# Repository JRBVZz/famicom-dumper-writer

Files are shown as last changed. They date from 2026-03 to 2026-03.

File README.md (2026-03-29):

### Famicom Dumper - дампер/программатор для картриджей Famicom/Dendy

Цель проекта — создание идеального симулятора шины данных Famicom. Он использует очень точную симуляцию цикла M2 и FSMC для доступа к памяти PRG и CHR. Кроме того, этот дампер имеет высокую скорость чтения/записи больших многоигровок.  
  
Главные отличия данного форка от оригинального проекта: полностью изменена трассировка; выводные светодиоды заменены на SMD; есть возможность установки на выбор THT или SMD версии кварцевого резонатора; убран разъем NES.  
  
В папке **STM32-Dumper** находится KiCad проект и гербер файлы для производства.  
  
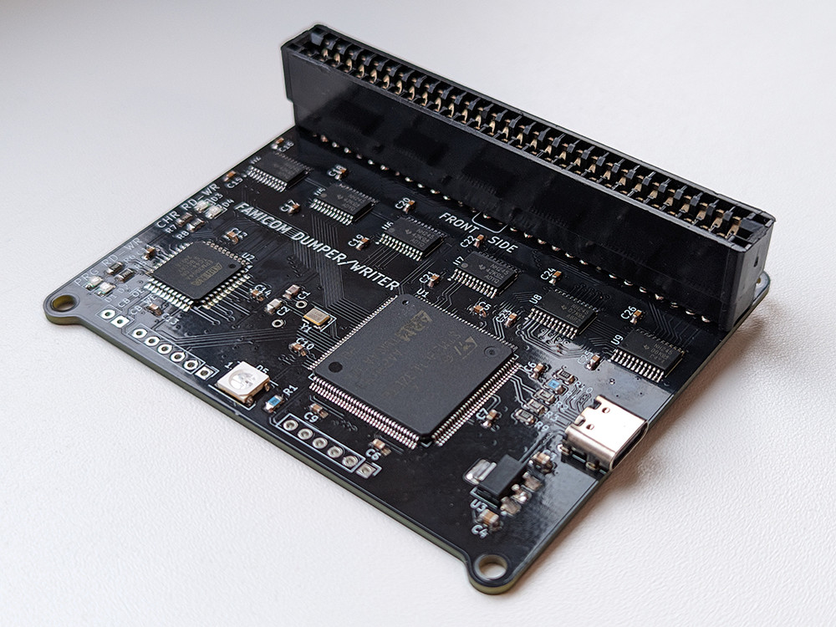
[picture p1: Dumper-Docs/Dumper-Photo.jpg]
Dumper-Photo

  
Проект создан в [**KiCad 9**](https://www.kicad.org/).

### Сборка

#### BoM и Schematic
[BoM](Dumper-Docs/Dumper-BOM.jpg)  
  
[Schematic](Dumper-Docs/STM32-Dumper-Schematic.pdf)

Выберите какой кварцевый резонатор ставить - SMD **Y1**, или THT **Y2**.  
Вместо шифтера **U7** можно установить два резистора **R11, R12**.  

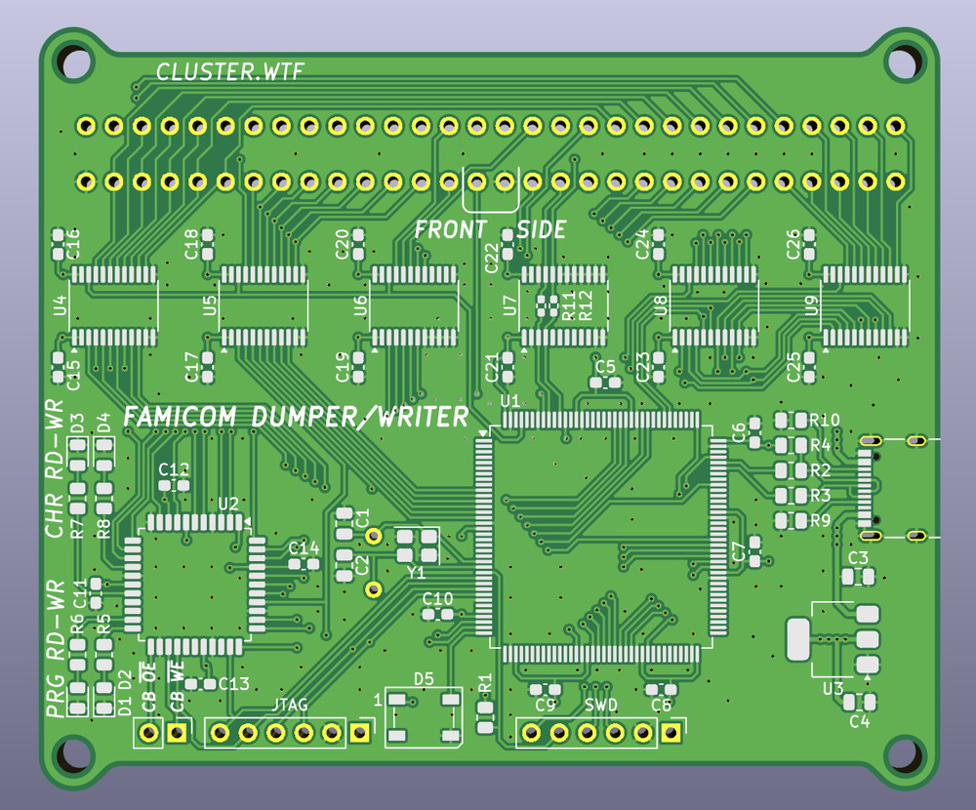
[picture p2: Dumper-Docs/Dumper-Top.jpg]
Dumper-Top


#### Firmware
В папке **Dumper-Firmware** находятся файлы для прошивки STM32 и EPM3064:  
**FamicomDumper.pof** - файл для прошивки EPM3064 с помощью USB-Blaster. Исходники находятся в архиве Dumper-CPLD.zip  
**FamicomDumperBootloader.bin** - бутлоадер для STM32, для прошивки можно использовать программу STM32 ST-LINK Utility и дешёвый донгл ST-LINK. Вручную укажите адрес для записи **0x08000000**.  
**FamicomDumper.bin** - основная программа для STM32. Вручную укажите адрес для записи **0x08040000**.  

### Software

[https://github.com/ClusterM/famicom-dumper-client](https://github.com/ClusterM/famicom-dumper-client)

#### P.S.

Мне не очень нравится идея преобразования сигналов до уровня 5В. Да, для старых картриджей это нормально, но современные дешевые многоигровки используют чипы с питанием 3.3В и в подавляющем большинстве случаев не имеют преобразователей уровней. Поэтому 5В сигналы для них, мягко говоря, не полезны. Как вариант, использовать 74LVC245A вместо 74LVC8T245.

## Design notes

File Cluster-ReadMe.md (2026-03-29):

# Famicom/NES Dumper/Writer

## Overview

This is a powerfull dumper/writer for Famicom/NES cartridges and Famicom Disc System cards. The goal of the project is to create an ideal famicom data bus simulator. It's using a very accurate M2 cycle simulation and FSMC (Flexible Static Memory Controller) to access PRG and CHR memory. FSMC is precisely synchronized with the M2 clock signal using a CPLD chip. Also, this device is very fast.





COOLBOY writing using GPIO pins

Video about dumper development (English subtitles):

Video preview (https://youtu.be/j_rteVX5q-g)

You can use it to:

* Dump cartridges, so you can play copy of your cartridge on emulator.
* Dump reset-based cartridges, there is command to simulate reset press.
* Dump cartridges that requires a continuous clock on M2 pin.
* Use it with [very flexible and multiplatform client](https://github.com/ClusterM/famicom-dumper-client), it's using C# scripts.
* Read/write battery backed saves, so that you can continue your saved game on emulator/console and vice-versa.
* (Re)write [COOLGIRL](https://github.com/ClusterM/coolgirl-famicom-multicard) cartridges.
* (Re)write ultracheap chinese [COOLBOY (AA6023 chip based)](https://www.nesdev.org/wiki/NES_2.0_Mapper_268) cartridges (mapper 268). Soldering is required for a cheap cartridges but it's very simple. Some more expensive cartridges can be rewritten without soldering.
* (Re)write UNROM-512 cartridges (RetroUSB, mapper 30).
* Read and write Famicom Disk System cards using FDS drive with the RAM adapter.
* Test your cartridges.
* Do some reverse engineering.
* Anything else that requires Famicom/NES bus simulation.

## Schematic

Schematic

Bill of Materials:

BoM

## Firmware

You need to write firmware to two chips: the STM32F103ZET microcontroller and the EPM3064 CPLD. But actually you need only to flash bootloader to STM32 using ST-Link programmer. Using bootloader you can flash both firmwares: to the STM32F103ZET and to the EPM3064.

How to use bootloader:
* Disconnect device from USB.
* Short the ground and the IRQ pins using tweezers or scissors.

* Connect the device to the USB of your PC/Mac. The RGB LED should turn green. Try again if it's not green.
* Remove tweezers/scissors quickly while the LED is green.
* The LED should turn yellow. Try again if it's not yellow.
* The device should be detected as USB drive.
* Format it to FAT32 if it's not formatted yet. You need to do it only once.
* Write SVF file with the firmware for the EPM3064 chip and BIN file with the firmware for the STM32F103ZET chip to this USB drive. You can write both at the same time.
* The RGB LED should turn white.
* Wait for some time: ~30 seconds for EPM3064 firmware, ~1 second for STM32F103ZET firmware.
* The RGB LED should turn green on success, red on some error.
* Reconnect device to your PC/Mac.

You can update the firmwares using the same way without any additional hardware (only tweezers or scissors :))

## Driver

This device shound work without any additional drivers on all modern operating systems, as virtual serial port.

## Software

[https://github.com/ClusterM/famicom-dumper-client](https://github.com/ClusterM/famicom-dumper-client)

## Donate
PayPal: cluster@cluster.wtf

https://www.donationalerts.com/r/clustermeerkat

https://boosty.to/cluster

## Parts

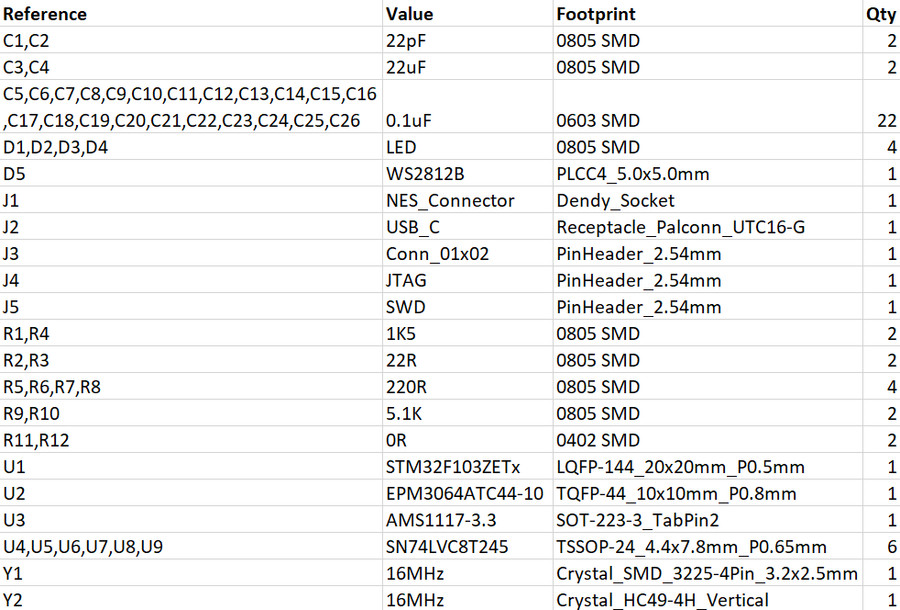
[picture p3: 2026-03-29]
Dumper-Docs/Dumper-BOM.jpg

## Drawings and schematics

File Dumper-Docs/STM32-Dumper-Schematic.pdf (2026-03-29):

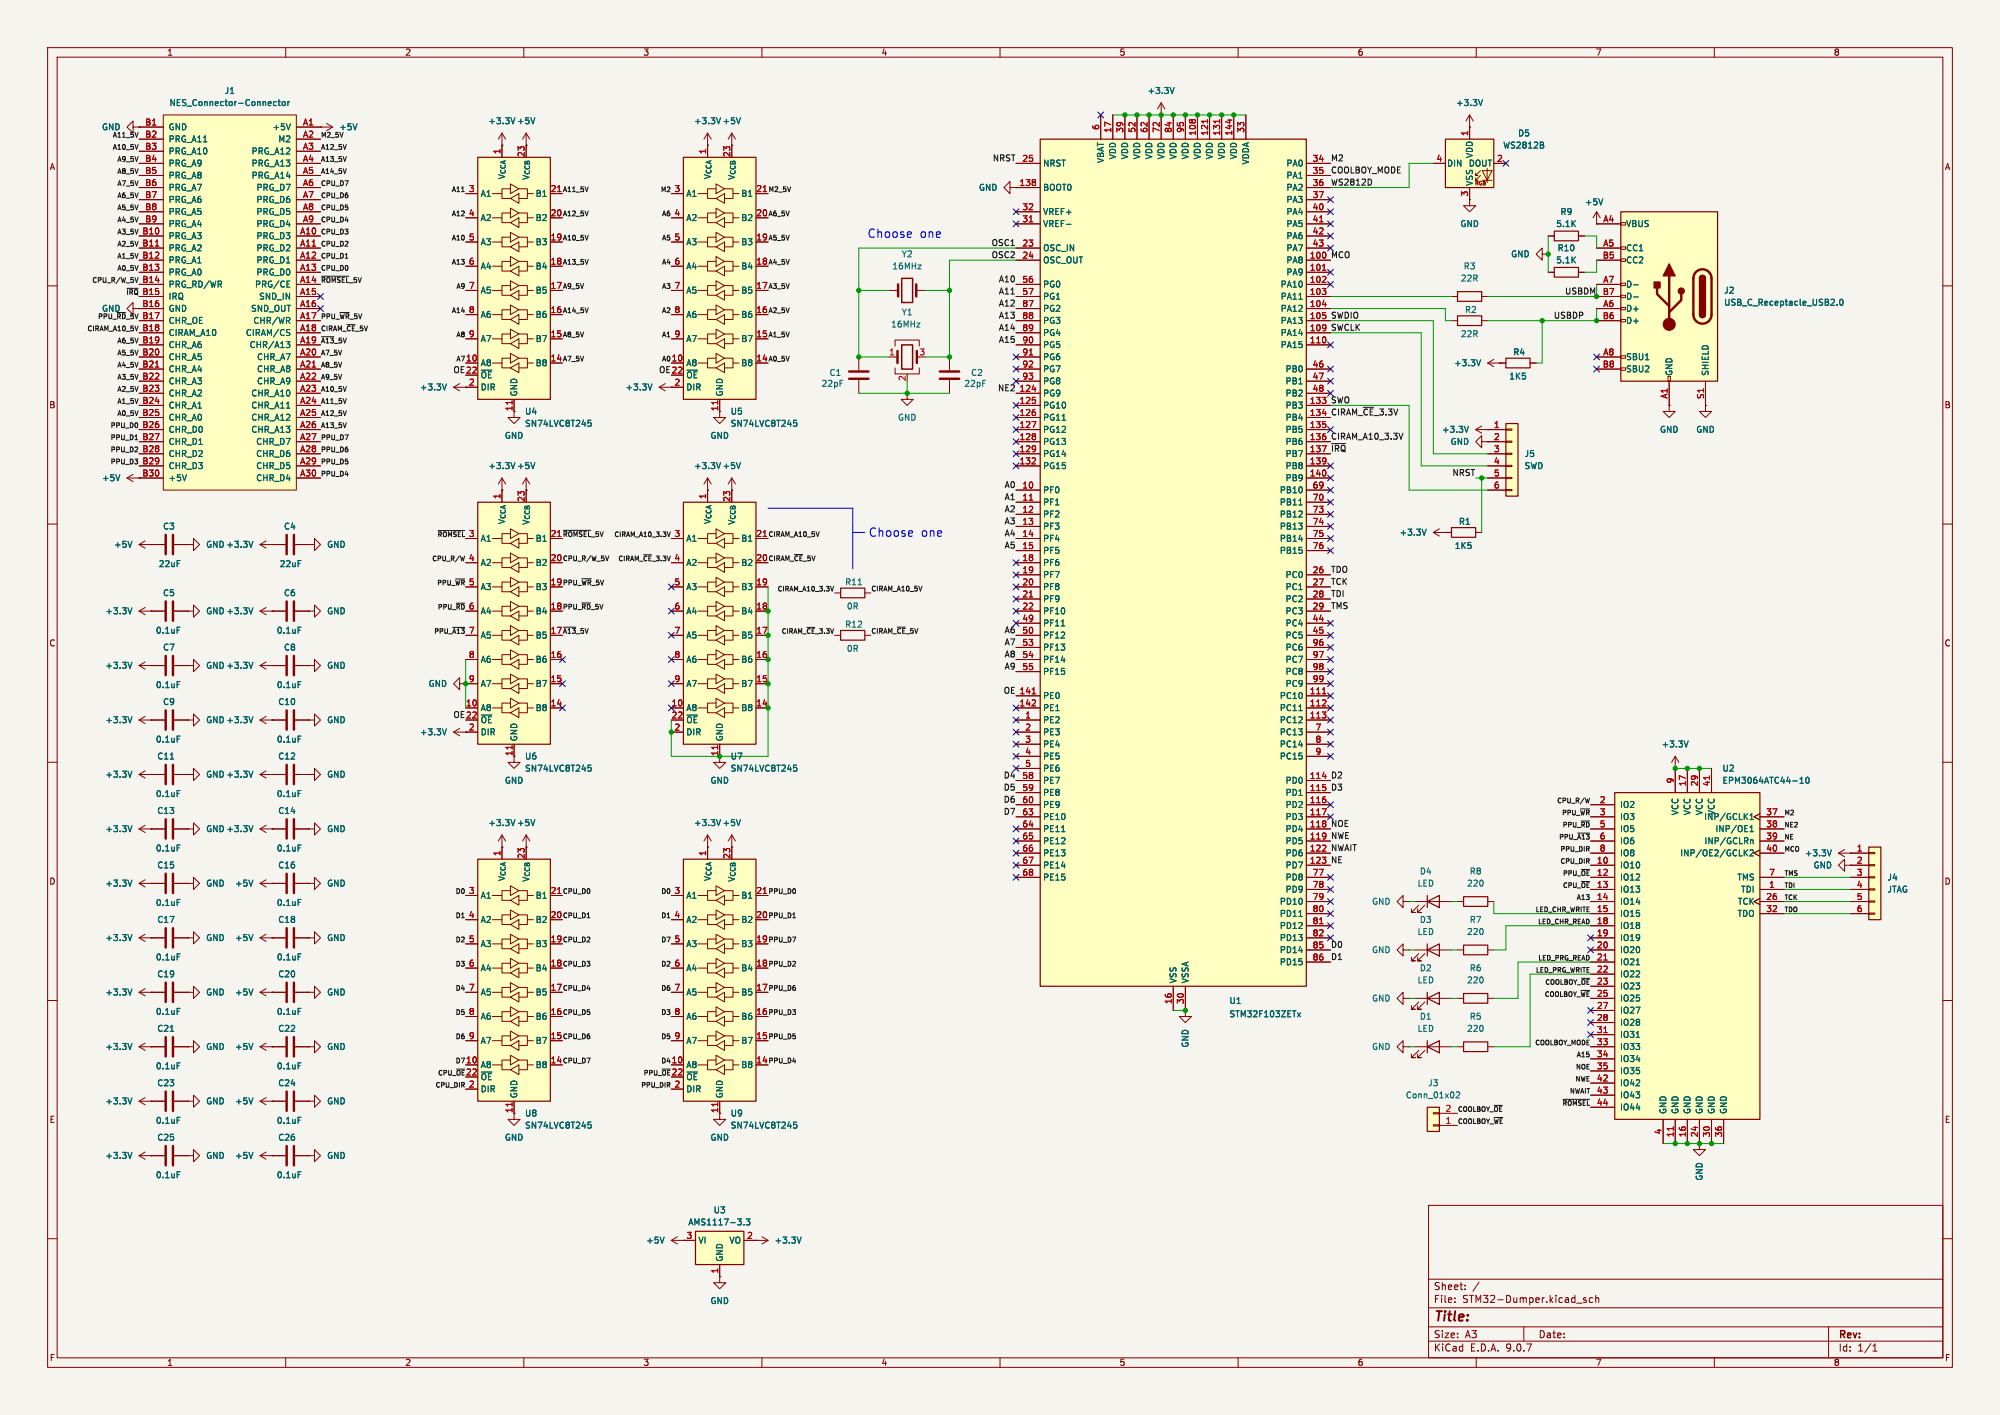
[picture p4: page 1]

6 VDD 17 VDD 39 VDD 52 VDD 62 VDD 72 VDD 84 VSS 16 VDD 95 VSSA 30 VDD 108 VDD 121 VDD 131 VDD 144 VDDA 33 PA0 34 PA1 35 PA2 36 PA3 37 PA4 40 PA5 41 PA6 42 PA7 43 PA8 100 PA9 101 PA10 102 PA11 103 PA12 104 PA13 105 PA14 109 PA15 110 PB0 46 PB1 47 PB2 48 PB3 133 PB4 134 PB5 135 PB6 136 PB7 137 PB8 139 PB9 140 PB10 69 PB11 70 PB12 73 PB13 74 PB14 75 PB15 76 PC0 26 PC1 27 PC2 28 PC3 29 PC4 44 PC5 45 PC6 96 PC7 97 PC8 98 PC9 99 PC10 111 PC11 112 PC12 113 PC13 7 PC14 8 PC15 9 PD0 114 PD1 115 PD2 116 PD3 117 PD4 118 PD5 119 PD6 122 PD7 123 PD8 77 PD9 78 PD10 79 PD11 80 PD12 81 PD13 82 PD14 85 PD15 86 U1STM32F103ZETx GND

6 VDD 17 VDD 39 VDD 52 VDD 62 VDD 72 VDD 84 VSS 16 VDD 95 VSSA 30 VDD 108 VDD 121 VDD 131 VDD 144 VDDA 33 PA0 34 PA1 35 PA2 36 PA3 37 PA4 40 PA5 41 PA6 42 PA7 43 PA8 100 PA9 101 PA10 102 PA11 103 PA12 104 PA13 105 PA14 109 PA15 110 PB0 46 PB1 47 PB2 48 PB3 133 PB4 134 PB5 135 PB6 136 PB7 137 PB8 139 PB9 140 PB10 69 PB11 70 PB12 73 PB13 74 PB14 75 PB15 76 PC0 26 PC1 27 PC2 28 PC3 29 PC4 44 PC5 45 PC6 96 PC7 97 PC8 98 PC9 99 PC10 111 PC11 112 PC12 113 PC13 7 PC14 8 PC15 9 PD0 114 PD1 115 PD2 116 PD3 117 PD4 118 PD5 119 PD6 122 PD7 123 PD8 77 PD9 78 PD10 79 PD11 80 PD12 81 PD13 82 PD14 85 PD15 86 GND

9 GND 11 VCC 17 GND 16 VCC 29 GND 24 VCC 41 GND 30 GND 36

1 VO 2 +3.3V U8SN74LVC8T245 A1 3 A2 4 A3 5 A4 6 A5 7 A6 8 A7 9 A8 10 ~{OE} 22 DIR 2 V_{CCA} 1 GND 11 V_{CCB} 23 B1 21 B2 20 B3 19 B4 18 B5 17 B6 16 B7 15 B8 14 GND

Id: 1/1 Title: File: STM32-Dumper.kicad_sch Sheet: /

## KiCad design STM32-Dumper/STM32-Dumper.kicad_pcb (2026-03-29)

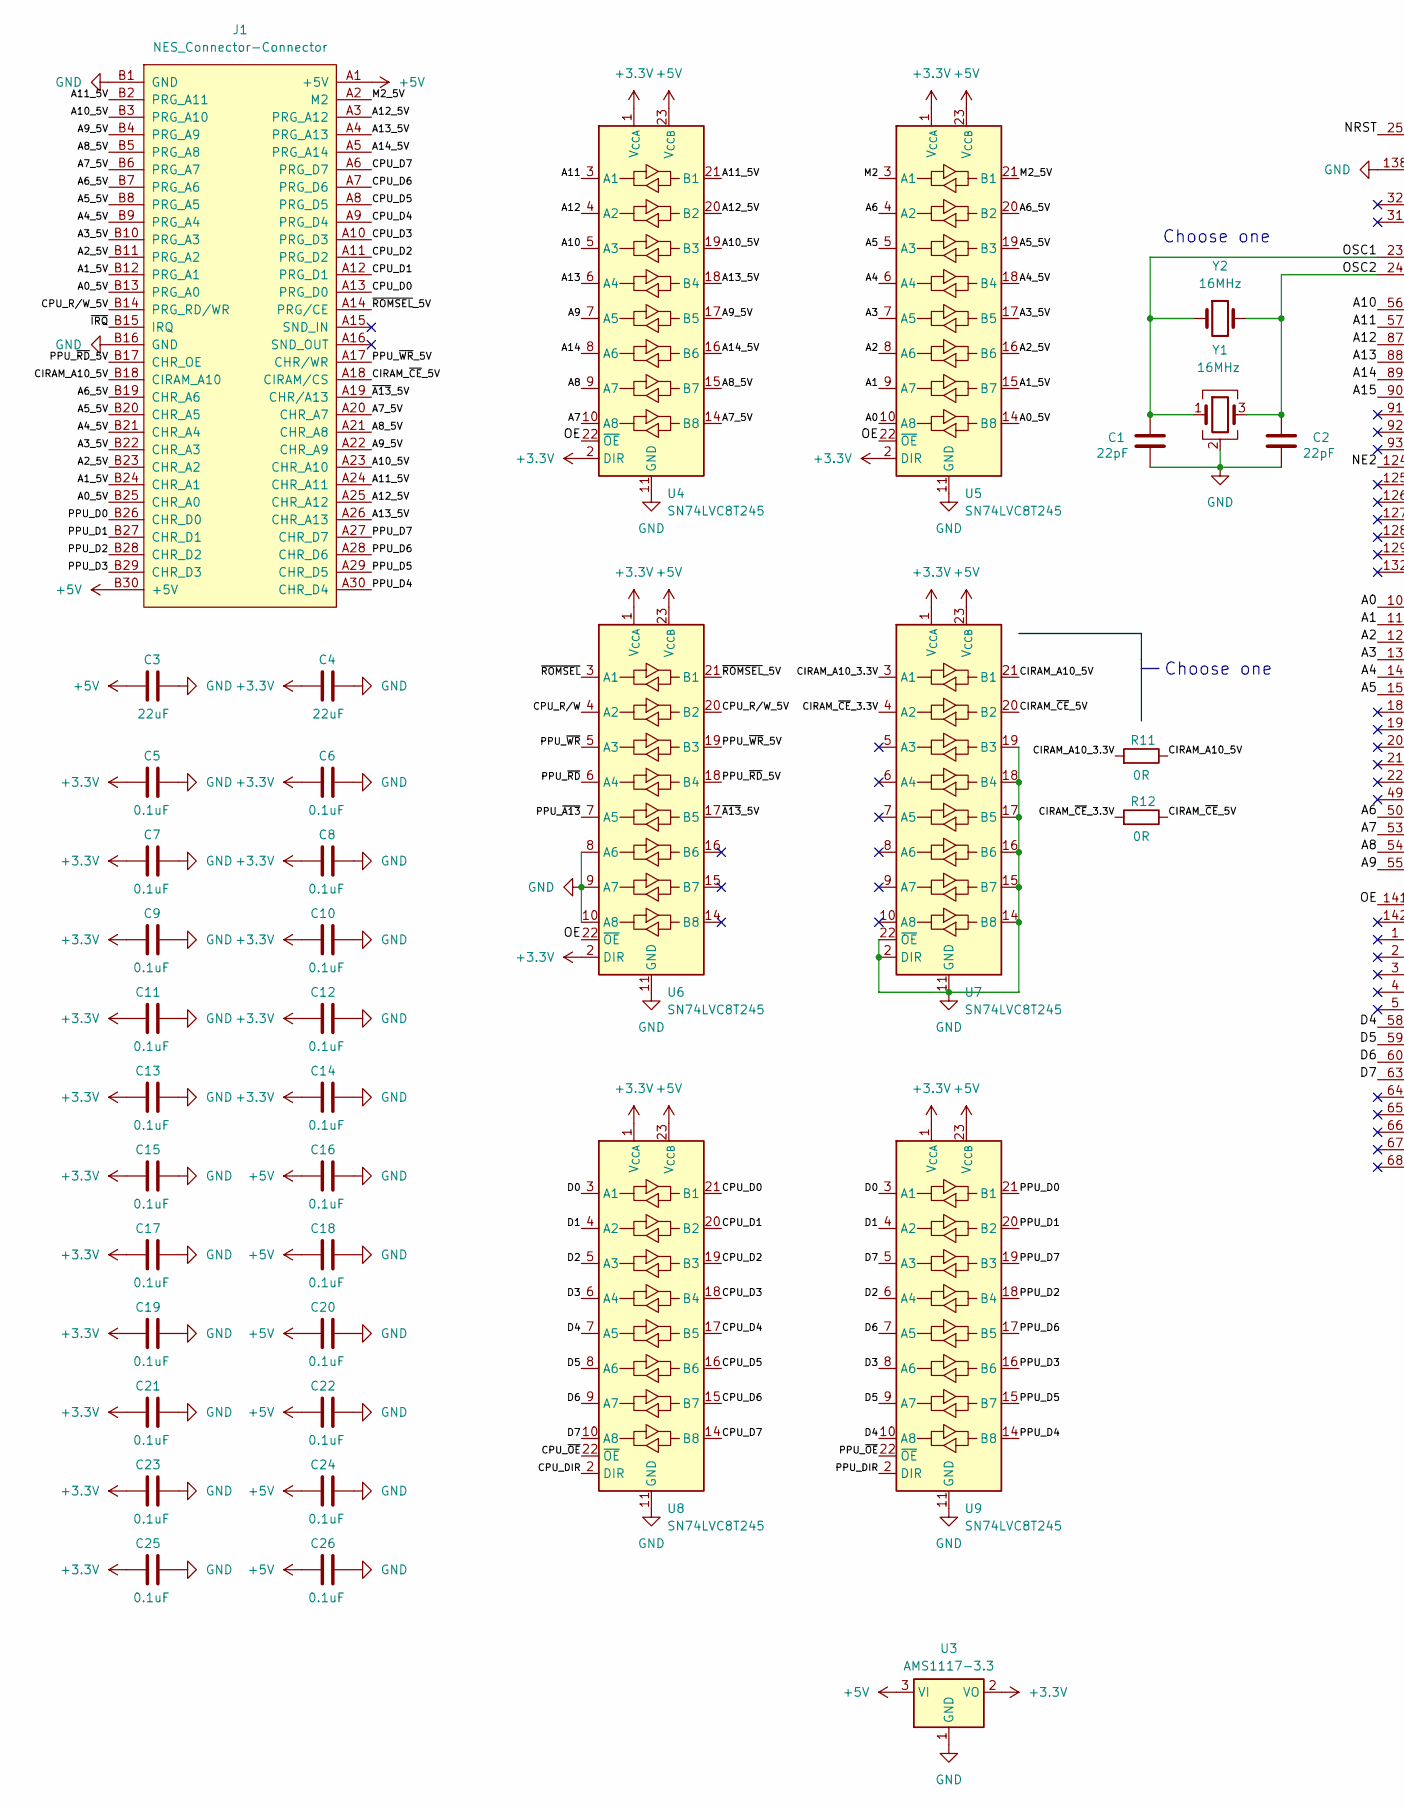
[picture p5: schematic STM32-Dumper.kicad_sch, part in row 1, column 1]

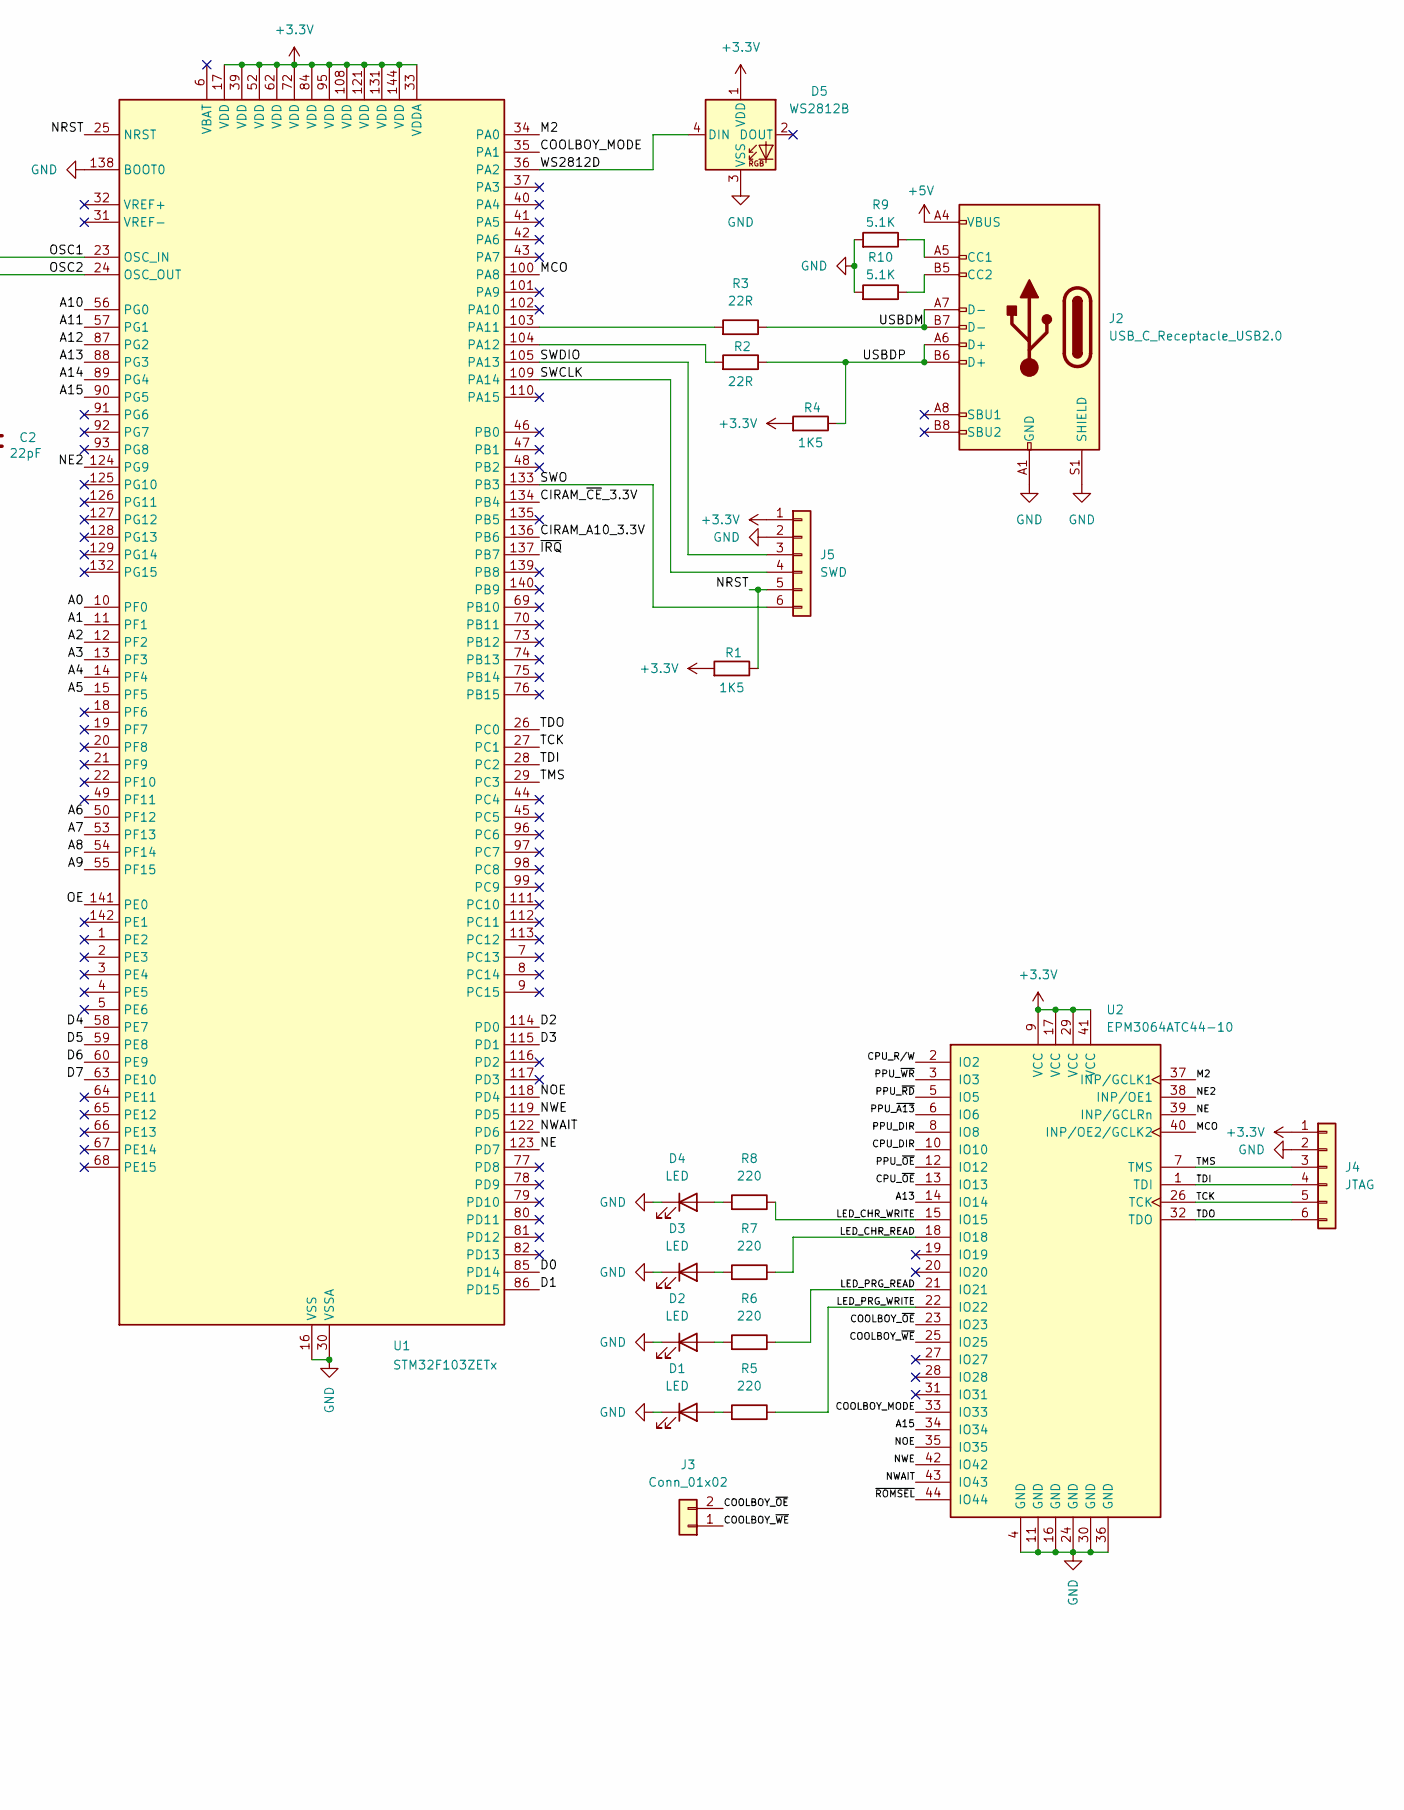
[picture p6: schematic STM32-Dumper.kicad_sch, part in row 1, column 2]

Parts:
C1, C2: 22pF; C_0805_2012Metric
C3, C4: 22uF; C_0805_2012Metric
C5, C6, C7, C8, C9, C10, C11, C12, C13, C14, C15, C16, C17, C18, C19, C20, C21, C22, C23, C24, C25, C26: 0.1uF; C_0603_1608Metric_Pad1.08x0.95mm_HandSolder
D1, D2, D3, D4: LED; LED_0805_2012Metric
D5: WS2812B; LED_WS2812B_PLCC4_5.0x5.0mm_P3.2mm
J1: NES_Connector-Connector; Dendy_Socket
J2: USB_C_Receptacle_USB2.0; USB_C_Receptacle_Palconn_UTC16-G
J3: Conn_01x02; PinHeader_1x02_P2.54mm_Vertical
J4: JTAG; PinHeader_1x06_P2.54mm_Vertical
J5: SWD; PinHeader_1x06_P2.54mm_Vertical
R1, R4: 1K5; R_0805_2012Metric
R2, R3: 22R; R_0805_2012Metric
R5, R6, R7, R8: 220; R_0805_2012Metric
R9, R10: 5.1K; R_0805_2012Metric
R11, R12: 0R; R_0402_1005Metric_Pad0.72x0.64mm_HandSolder
U1: STM32F103ZETx; LQFP-144_20x20mm_P0.5mm
U2: EPM3064ATC44-10; TQFP-44_10x10mm_P0.8mm
U3: AMS1117-3.3; SOT-223-3_TabPin2
U4, U5, U6, U7, U8, U9: SN74LVC8T245; TSSOP-24_4.4x7.8mm_P0.65mm
Y1: 16MHz; Crystal_SMD_3225-4Pin_3.2x2.5mm
Y2: 16MHz; Crystal_HC49-4H_Vertical

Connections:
+3.3V: C4.1, C5.1, C6.1, C7.1, C8.1, C9.1, C10.1, C11.1, C12.1, C13.1, C14.1, C15.1, C17.1, C19.1, C21.1, C23.1, C25.1, D5.1 (VDD), J4.1, J5.1, R1.2, R4.2, U1.17 (VDD), U1.33 (VDDA), U1.39 (VDD), U1.52 (VDD), U1.62 (VDD), U1.72 (VDD), U1.84 (VDD), U1.95 (VDD), U1.108 (VDD), U1.121 (VDD), U1.131 (VDD), U1.144 (VDD), U2.9 (VCC), U2.17 (VCC), U2.29 (VCC), U2.41 (VCC), U3.2 (VO), U4.1 (V_{CCA}), U4.2 (DIR), U5.1 (V_{CCA}), U5.2 (DIR), U6.1 (V_{CCA}), U6.2 (DIR), U7.1 (V_{CCA}), U8.1 (V_{CCA}), U9.1 (V_{CCA})
+5V: C3.1, C16.1, C18.1, C20.1, C22.1, C24.1, C26.1, J1.A1 (+5V), J1.B30 (+5V), J2.A4 (VBUS), J2.A9 (VBUS), J2.B4 (VBUS), J2.B9 (VBUS), U3.3 (VI), U4.23 (V_{CCB}), U4.24 (V_{CCB}), U5.23 (V_{CCB}), U5.24 (V_{CCB}), U6.23 (V_{CCB}), U6.24 (V_{CCB}), U7.23 (V_{CCB}), U7.24 (V_{CCB}), U8.23 (V_{CCB}), U8.24 (V_{CCB}), U9.23 (V_{CCB}), U9.24 (V_{CCB})
/A0: U1.10 (PF0), U5.10 (A8)
/A0_5V: J1.B13 (PRG_A0), J1.B25 (CHR_A0), U5.14 (B8)
/A1: U1.11 (PF1), U5.9 (A7)
/A1_5V: J1.B12 (PRG_A1), J1.B24 (CHR_A1), U5.15 (B7)
/A2: U1.12 (PF2), U5.8 (A6)
/A2_5V: J1.B11 (PRG_A2), J1.B23 (CHR_A2), U5.16 (B6)
/A3: U1.13 (PF3), U5.7 (A5)
/A3_5V: J1.B10 (PRG_A3), J1.B22 (CHR_A3), U5.17 (B5)
/A4: U1.14 (PF4), U5.6 (A4)
/A4_5V: J1.B9 (PRG_A4), J1.B21 (CHR_A4), U5.18 (B4)
/A5: U1.15 (PF5), U5.5 (A3)
/A5_5V: J1.B8 (PRG_A5), J1.B20 (CHR_A5), U5.19 (B3)
/A6: U1.50 (PF12), U5.4 (A2)
/A6_5V: J1.B7 (PRG_A6), J1.B19 (CHR_A6), U5.20 (B2)
/A7: U1.53 (PF13), U4.10 (A8)
/A7_5V: J1.A20 (CHR_A7), J1.B6 (PRG_A7), U4.14 (B8)
/A8: U1.54 (PF14), U4.9 (A7)
/A8_5V: J1.A21 (CHR_A8), J1.B5 (PRG_A8), U4.15 (B7)
/A9: U1.55 (PF15), U4.7 (A5)
/A9_5V: J1.A22 (CHR_A9), J1.B4 (PRG_A9), U4.17 (B5)
/A10: U1.56 (PG0), U4.5 (A3)
/A10_5V: J1.A23 (CHR_A10), J1.B3 (PRG_A10), U4.19 (B3)
/A11: U1.57 (PG1), U4.3 (A1)
/A11_5V: J1.A24 (CHR_A11), J1.B2 (PRG_A11), U4.21 (B1)
/A12: U1.87 (PG2), U4.4 (A2)
/A12_5V: J1.A3 (PRG_A12), J1.A25 (CHR_A12), U4.20 (B2)
/A13: U1.88 (PG3), U2.14 (IO14), U4.6 (A4)
/A13_5V: J1.A4 (PRG_A13), J1.A26 (CHR_A13), U4.18 (B4)
/A14: U1.89 (PG4), U4.8 (A6)
/A14_5V: J1.A5 (PRG_A14), U4.16 (B6)
/A15: U1.90 (PG5), U2.34 (IO34)
/CIRAM_A10_3.3V: R11.2, U1.136 (PB6), U7.3 (A1)
/CIRAM_A10_5V: J1.B18 (CIRAM_A10), R11.1, U7.21 (B1)
/CIRAM_~CE_3.3V: R12.2, U1.134 (PB4), U7.4 (A2)
/CIRAM_~CE_5V: J1.A18 (CIRAM/CS), R12.1, U7.20 (B2)
/COOLBOY_MODE: U1.35 (PA1), U2.33 (IO33)
/COOLBOY_~OE: J3.2, U2.23 (IO23)
/COOLBOY_~WE: J3.1, U2.25 (IO25)
/CPU_D0: J1.A13 (PRG_D0), U8.21 (B1)
/CPU_D1: J1.A12 (PRG_D1), U8.20 (B2)
/CPU_D2: J1.A11 (PRG_D2), U8.19 (B3)
/CPU_D3: J1.A10 (PRG_D3), U8.18 (B4)
/CPU_D4: J1.A9 (PRG_D4), U8.17 (B5)
/CPU_D5: J1.A8 (PRG_D5), U8.16 (B6)
/CPU_D6: J1.A7 (PRG_D6), U8.15 (B7)
/CPU_D7: J1.A6 (PRG_D7), U8.14 (B8)
/CPU_DIR: U2.10 (IO10), U8.2 (DIR)
/CPU_R/W: U2.2 (IO2), U6.4 (A2)
/CPU_R/W_5V: J1.B14 (PRG_RD/WR), U6.20 (B2)
/CPU_~OE: U2.13 (IO13), U8.22 (~OE)
/D0: U1.85 (PD14), U8.3 (A1), U9.3 (A1)
/D1: U1.86 (PD15), U8.4 (A2), U9.4 (A2)
/D2: U1.114 (PD0), U8.5 (A3), U9.6 (A4)
/D3: U1.115 (PD1), U8.6 (A4), U9.8 (A6)
/D4: U1.58 (PE7), U8.7 (A5), U9.10 (A8)
/D5: U1.59 (PE8), U8.8 (A6), U9.9 (A7)
/D6: U1.60 (PE9), U8.9 (A7), U9.7 (A5)
/D7: U1.63 (PE10), U8.10 (A8), U9.5 (A3)
/LED_CHR_READ: R7.1, U2.18 (IO18)
/LED_CHR_WRITE: R8.1, U2.15 (IO15)
/LED_PRG_READ: R6.1, U2.21 (IO21)
/LED_PRG_WRITE: R5.1, U2.22 (IO22)
/M2: U1.34 (PA0), U2.37 (INP/GCLK1), U5.3 (A1)
/M2_5V: J1.A2 (M2), U5.21 (B1)
/MCO: U1.100 (PA8), U2.40 (INP/OE2/GCLK2)
/NE: U1.123 (PD7), U2.39 (INP/GCLRn)
/NE2: U1.124 (PG9), U2.38 (INP/OE1)
/NOE: U1.118 (PD4), U2.35 (IO35)
/NRST: J5.5, R1.1, U1.25 (NRST)
/NWAIT: U1.122 (PD6), U2.43 (IO43)
/NWE: U1.119 (PD5), U2.42 (IO42)
/OE: U1.141 (PE0), U4.22 (~OE), U5.22 (~OE), U6.22 (~OE)
/OSC1: C1.2, U1.23 (OSC_IN), Y1.1, Y2.1
/OSC2: C2.2, U1.24 (OSC_OUT), Y1.3, Y2.2
/PPU_D0: J1.B26 (CHR_D0), U9.21 (B1)
/PPU_D1: J1.B27 (CHR_D1), U9.20 (B2)
/PPU_D2: J1.B28 (CHR_D2), U9.18 (B4)
/PPU_D3: J1.B29 (CHR_D3), U9.16 (B6)
/PPU_D4: J1.A30 (CHR_D4), U9.14 (B8)
/PPU_D5: J1.A29 (CHR_D5), U9.15 (B7)
/PPU_D6: J1.A28 (CHR_D6), U9.17 (B5)
/PPU_D7: J1.A27 (CHR_D7), U9.19 (B3)
/PPU_DIR: U2.8 (IO8), U9.2 (DIR)
/PPU_~A13: U2.6 (IO6), U6.7 (A5)
/PPU_~OE: U2.12 (IO12), U9.22 (~OE)
/PPU_~RD: U2.5 (IO5), U6.6 (A4)
/PPU_~RD_5V: J1.B17 (CHR_OE), U6.18 (B4)
/PPU_~WR: U2.3 (IO3), U6.5 (A3)
/PPU_~WR_5V: J1.A17 (CHR/WR), U6.19 (B3)
/SWCLK: J5.4, U1.109 (PA14)
/SWDIO: J5.3, U1.105 (PA13)
/SWO: J5.6, U1.133 (PB3)
/TCK: J4.5, U1.27 (PC1), U2.26 (TCK)
/TDI: J4.4, U1.28 (PC2), U2.1 (TDI)
/TDO: J4.6, U1.26 (PC0), U2.32 (TDO)
/TMS: J4.3, U1.29 (PC3), U2.7 (TMS)
/USBDM: J2.A7 (D-), J2.B7 (D-), R3.1
/USBDP: J2.A6 (D+), J2.B6 (D+), R2.1, R4.1
/WS2812D: D5.4 (DIN), U1.36 (PA2)
/~A13_5V: J1.A19 (CHR/A13), U6.17 (B5)
/~IRQ: J1.B15 (IRQ), U1.137 (PB7)
/~ROMSEL: U2.44 (IO44), U6.3 (A1)
/~ROMSEL_5V: J1.A14 (PRG/CE), U6.21 (B1)
GND: C1.1, C2.1, C3.2, C4.2, C5.2, C6.2, C7.2, C8.2, C9.2, C10.2, C11.2, C12.2, C13.2, C14.2, C15.2, C16.2, C17.2, C18.2, C19.2, C20.2, C21.2, C22.2, C23.2, C24.2, C25.2, C26.2, D1.1 (K), D2.1 (K), D3.1 (K), D4.1 (K), D5.3 (VSS), J1.B1 (GND), J1.B16 (GND), J2.A1 (GND), J2.A12 (GND), J2.B1 (GND), J2.B12 (GND), J2.S1 (SHIELD), J4.2, J5.2, R9.2, R10.2, U1.16 (VSS), U1.30 (VSSA), U1.38 (VSS), U1.51 (VSS), U1.61 (VSS), U1.71 (VSS), U1.83 (VSS), U1.94 (VSS), U1.107 (VSS), U1.120 (VSS), U1.130 (VSS), U1.138 (BOOT0), U1.143 (VSS), U2.4 (GND), U2.11 (GND), U2.16 (GND), U2.24 (GND), U2.30 (GND), U2.36 (GND), U3.1 (GND), U4.11 (GND), U4.12 (GND), U4.13 (GND), U5.11 (GND), U5.12 (GND), U5.13 (GND), U6.8 (A6), U6.9 (A7), U6.10 (A8), U6.11 (GND), U6.12 (GND), U6.13 (GND), U7.2 (DIR), U7.11 (GND), U7.12 (GND), U7.13 (GND), U7.14 (B8), U7.15 (B7), U7.16 (B6), U7.17 (B5), U7.18 (B4), U7.19 (B3), U7.22 (~OE), U8.11 (GND), U8.12 (GND), U8.13 (GND), U9.11 (GND), U9.12 (GND), U9.13 (GND), Y1.2 (G), Y1.4 (G)
unnamed: D1.2 (A), R5.2
unnamed: D2.2 (A), R6.2
unnamed: D3.2 (A), R7.2
unnamed: D4.2 (A), R8.2
unnamed: J2.A5 (CC1), R9.1
unnamed: J2.B5 (CC2), R10.1
unnamed: R3.2, U1.103 (PA11)
unnamed: R2.2, U1.104 (PA12)

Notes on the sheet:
Choose one

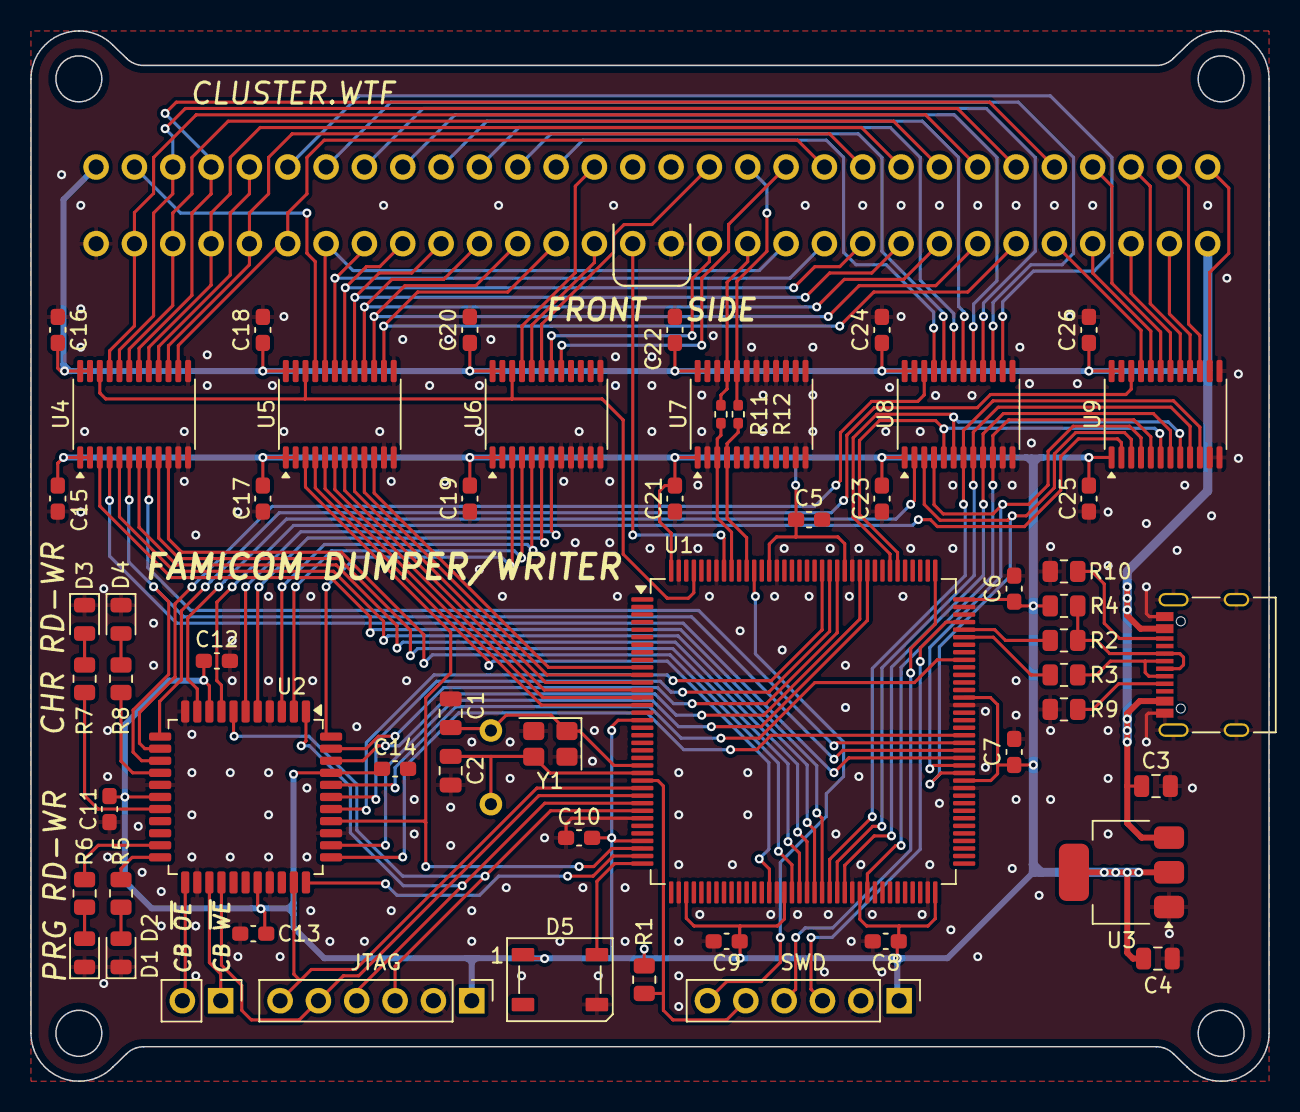
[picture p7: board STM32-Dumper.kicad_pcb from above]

Board: 2 copper layers, 82.0 x 69.6 mm, 59 parts (1 on the bottom side), 114 nets.
